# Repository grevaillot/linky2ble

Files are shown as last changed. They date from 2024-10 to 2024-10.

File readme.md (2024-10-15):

# linky2ble

stm32wb55 based linky teleinfo to ble bridge - based on https://fumeebleue.fr/ & https://hallard.me/pitinfov12/ designs

## Preview:

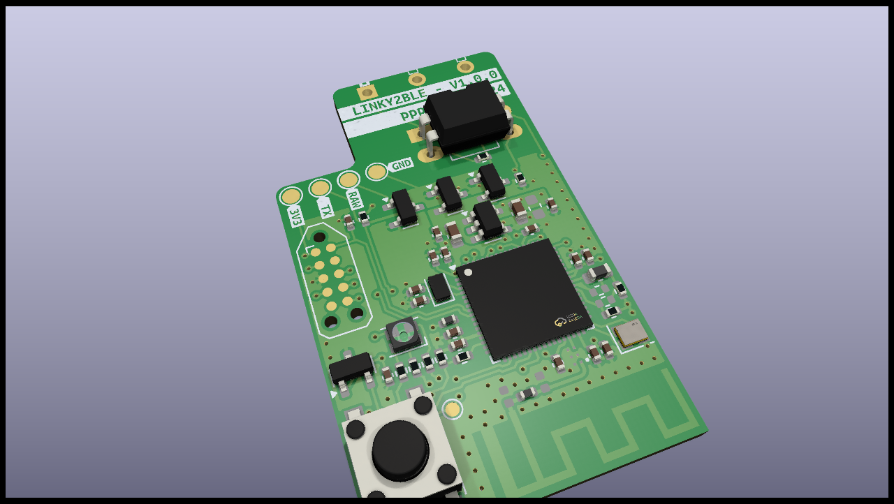
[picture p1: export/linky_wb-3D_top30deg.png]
board picture 30deg

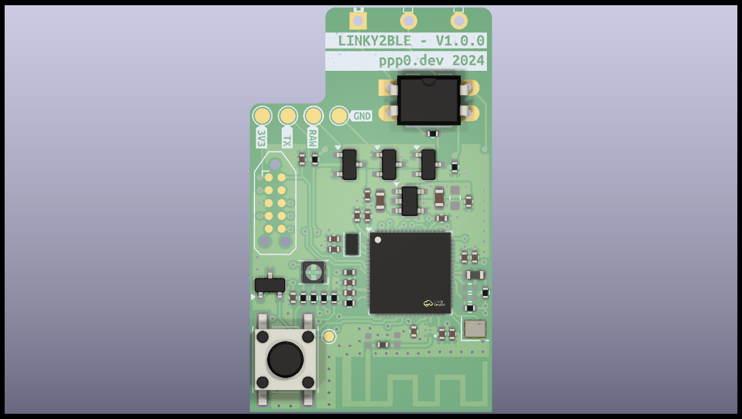
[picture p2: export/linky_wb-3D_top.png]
board picture top


## Schematics:

schematics here

## Aisler project:

https://aisler.net/p/WQYUVWAP (ordering a stencil is recommended :))

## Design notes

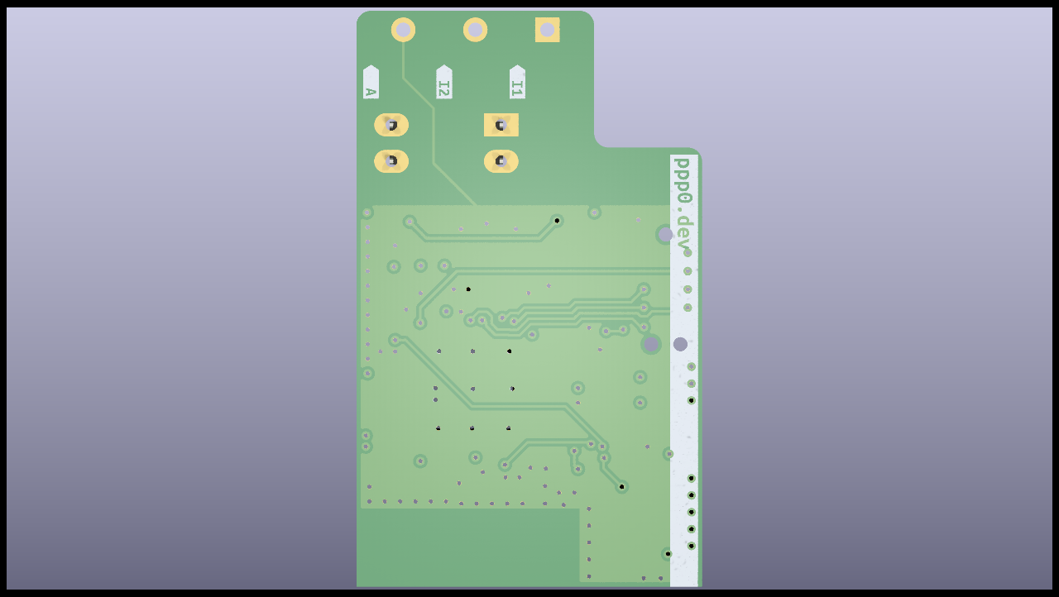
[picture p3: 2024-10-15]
export/linky_wb-3D_bottom.png

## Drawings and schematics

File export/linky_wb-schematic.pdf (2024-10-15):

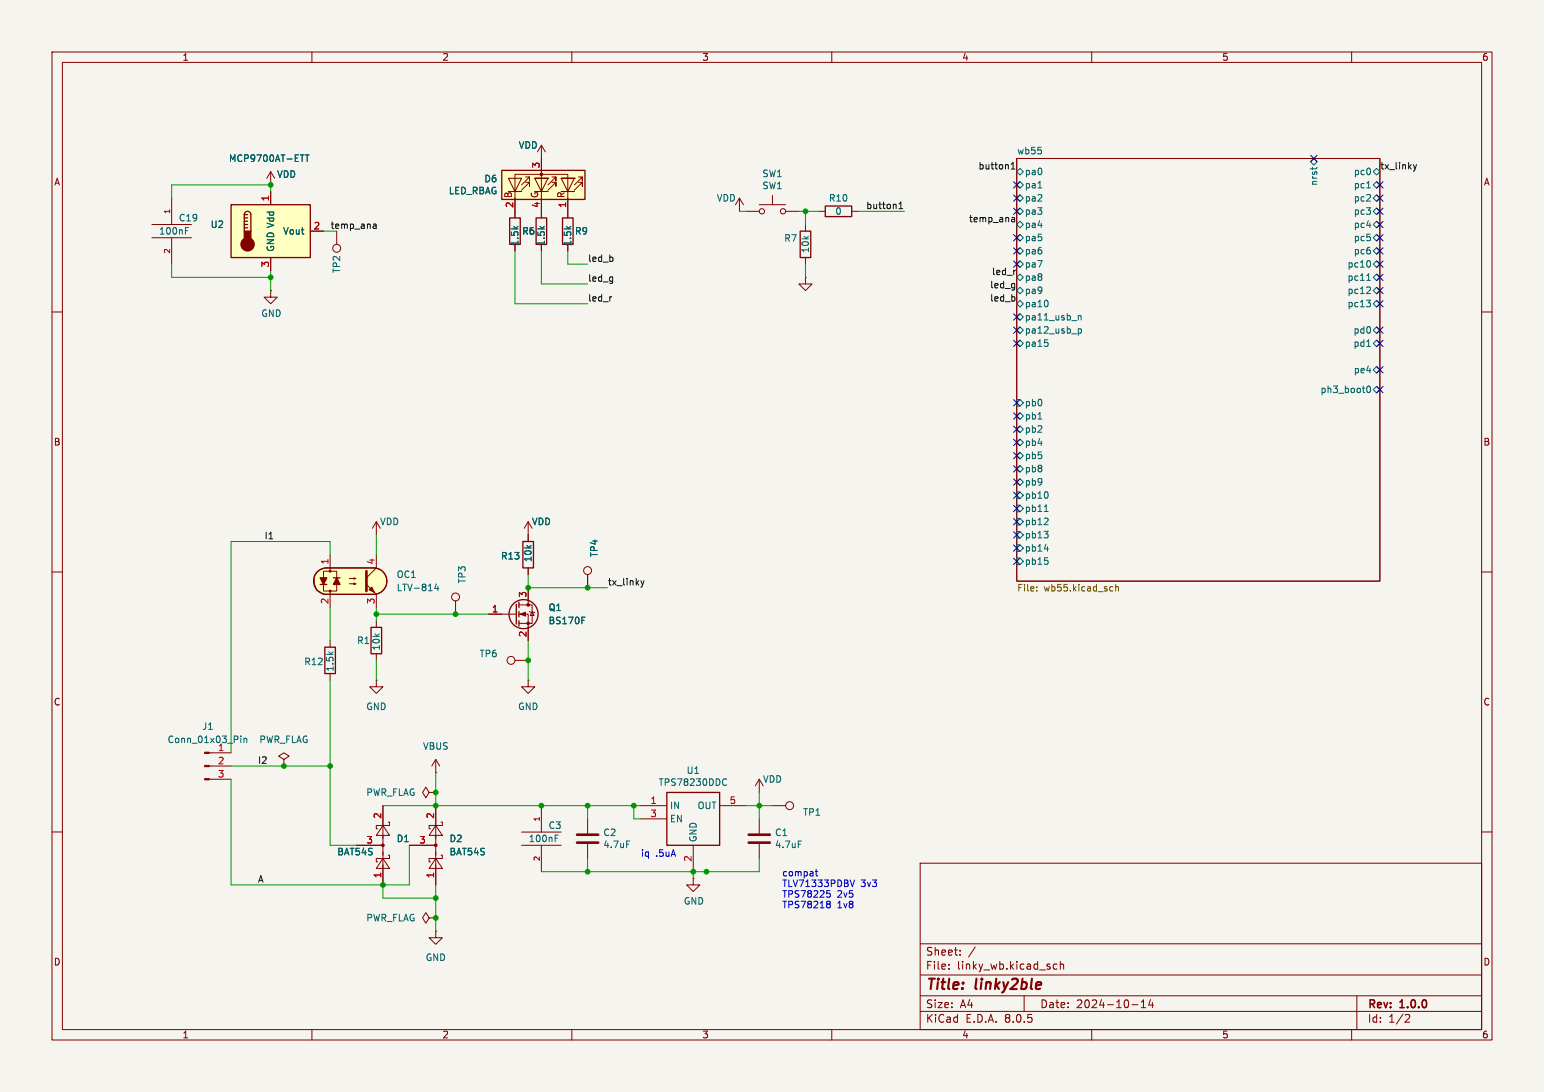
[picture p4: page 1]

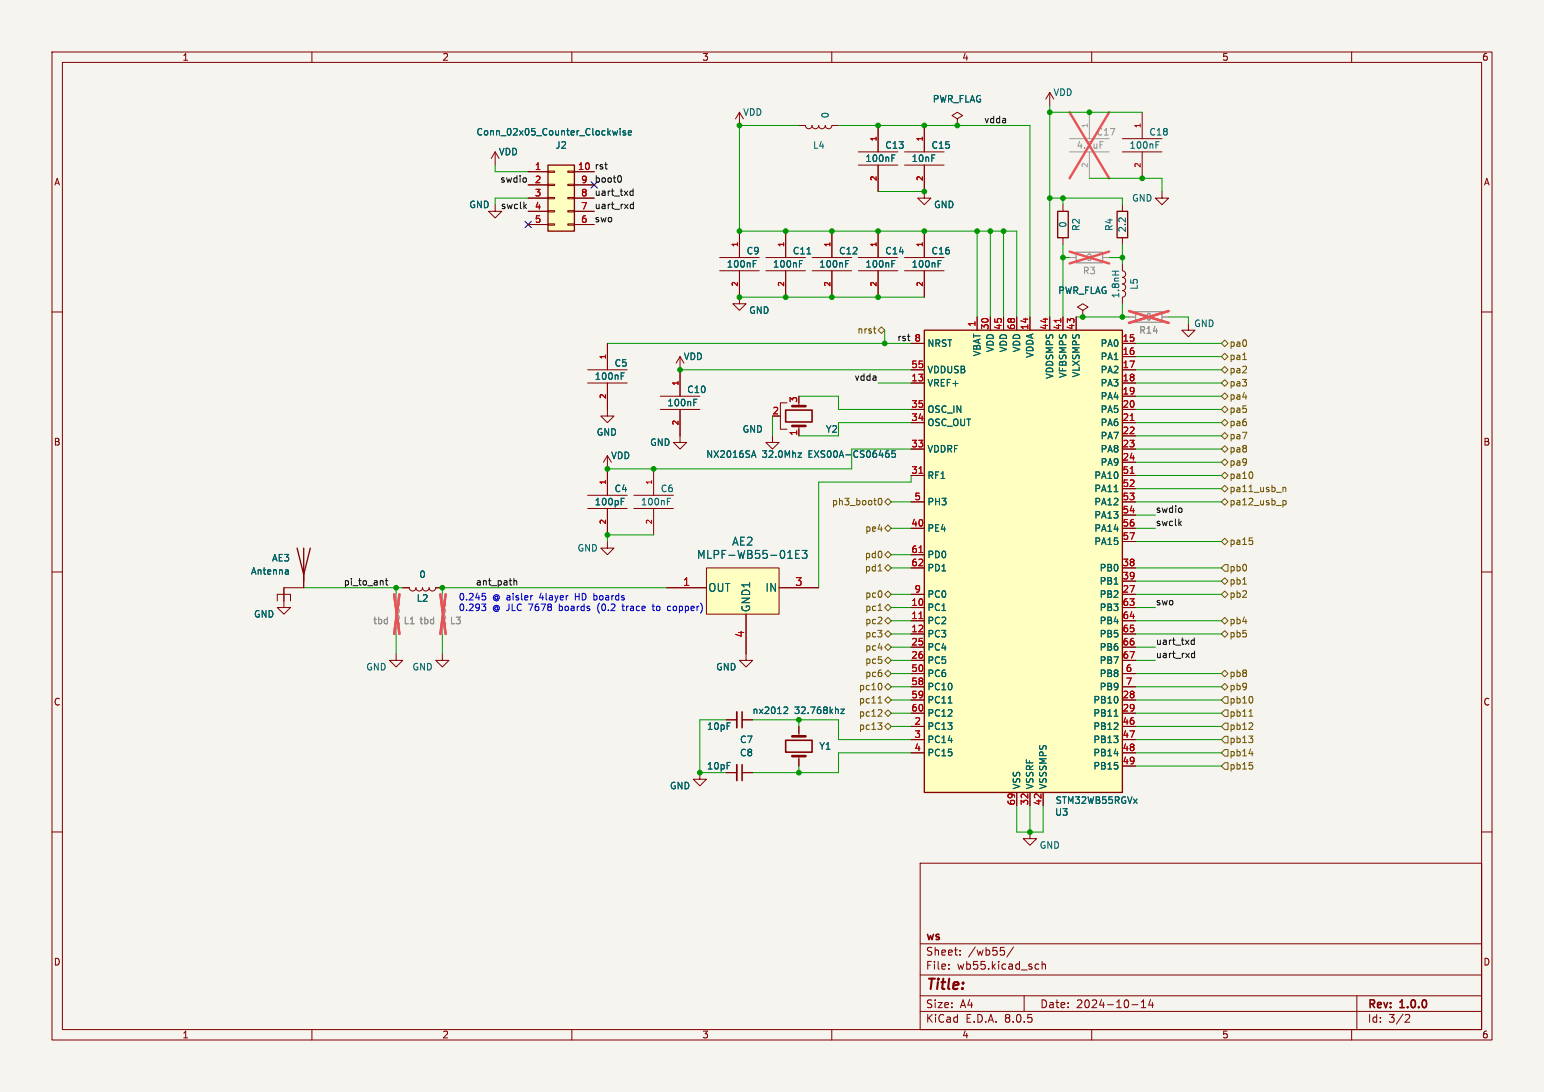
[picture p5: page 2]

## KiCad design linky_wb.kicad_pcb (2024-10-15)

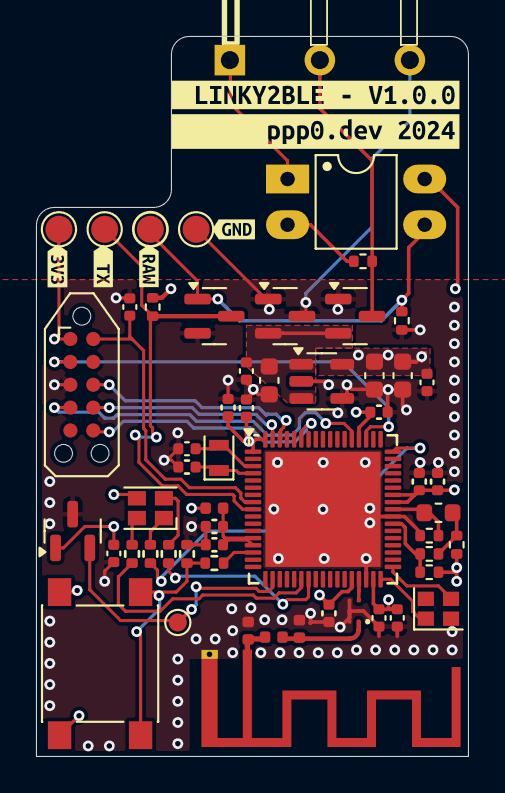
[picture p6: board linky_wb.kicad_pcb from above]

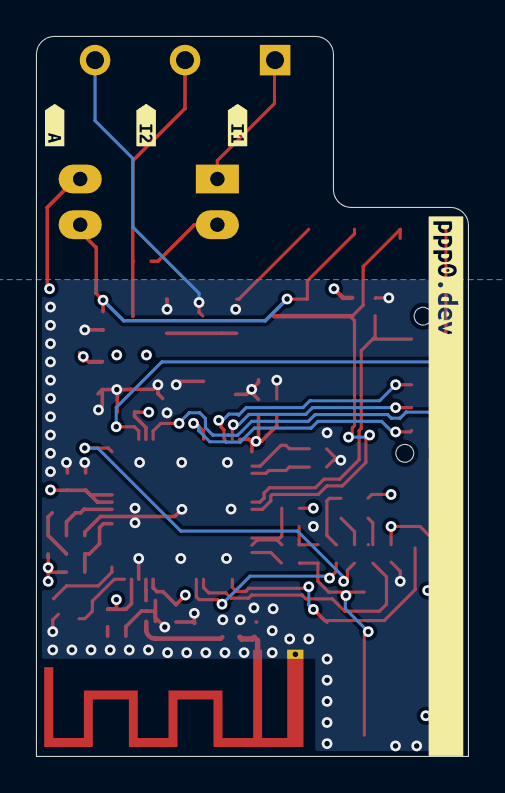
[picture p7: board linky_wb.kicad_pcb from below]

Board: 4 copper layers, 24.0 x 40.0 mm, 66 parts (4 on the bottom side), 34 nets.

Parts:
AE2: MLPF-WB55-01E3
AE3: Antenna; Texas_SWRA117D_2.4GHz_Left
C1, C2, C17: 4.7uF; C_0603_1608Metric
C3, C5, C6, C9, C10, C11, C12, C13, C14, C16, C18, C19: 100nF; C_0402_1005Metric
C4: 100pF; C_0402_1005Metric
C7, C8: 10pF; C_0402_1005Metric
C15: 10nF; C_0402_1005Metric
D1, D2: BAT54S; SOT-23
D6: LED_RBAG; LED_Cree-PLCC4_2x2mm_CW
J1: Conn_01x03_Pin; PinHeader_1x03_P2.54mm_Horizontal
J2: Conn_02x05_Counter_Clockwise; Tag-Connect_TC2050-IDC-NL_2x05_P1.27mm_Vertical
L1, L3: tbd; L_0402_1005Metric
L2, L4: 0; L_0402_1005Metric
L5: 1.8nH; L_0603_1608Metric
OC1: LTV-814; DIP-4_W7.62mm_LongPads
Q1: BS170F; SOT-23
R1, R7, R13: 10k; R_0402_1005Metric
R2, R3, R10, R14: 0; R_0402_1005Metric
R4: 2.2; R_0402_1005Metric
R5, R6, R9, R12: 1.5k; R_0402_1005Metric
SW1: SW1; SW_Push_1P1T_NO_6x6mm_H9.5mm
TP1, TP3, TP4, TP6: 5v; TestPoint_Pad_D1.5mm
TP2: TestPoint; TestPoint_Pad_D1.0mm
U1: TPS78230DDC; SOT-23-5
U2: MCP9700AT-ETT; SOT-23
U3: STM32WB55RGVx; QFN-68-1EP_8x8mm_P0.4mm_EP6.4x6.4mm
Y1: nx2012 32.768khz; Crystal_SMD_2012-2Pin_2.0x1.2mm
Y2: NX2016SA 32.0Mhz EXS00A-CS06465; Crystal_SMD_2016-4Pin_2.0x1.6mm
kibuzzard-670CFC0C: G***; kibuzzard-670CFC0C
kibuzzard-670CFC05: G***; kibuzzard-670CFC05
kibuzzard-670CFC68: G***; kibuzzard-670CFC68
kibuzzard-670CFCA8: G***; kibuzzard-670CFCA8
kibuzzard-670D18C1: G***; kibuzzard-670D18C1
kibuzzard-670D18F3: G***; kibuzzard-670D18F3
kibuzzard-670D046C: G***; kibuzzard-670D046C
kibuzzard-670D0302: G***; kibuzzard-670D0302
kibuzzard-670D0308: G***; kibuzzard-670D0308
kibuzzard-670D0311: G***; kibuzzard-670D0311

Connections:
/I1: J1.1, OC1.1
/I2: D1.3, J1.2, R12.2
/button1: R10.2, U3.15 (PA0)
/led_b: R9.1, U3.51 (PA10)
/led_g: R6.1, U3.24 (PA9)
/led_r: R5.1, U3.23 (PA8)
/temp_ana: TP2.1, U2.2 (Vout), U3.19 (PA4)
/tx_linky: Q1.3 (D), R13.2, TP4.1, U3.9 (PC0)
/wb55/ant_path: AE2.1 (OUT), L2.2, L3.2
/wb55/pi_to_ant: AE3.1 (A), L1.2, L2.1
/wb55/rst: C5.1, J2.10, U3.8 (NRST)
/wb55/swclk: J2.4, U3.56 (PA14)
/wb55/swdio: J2.2, U3.54 (PA13)
/wb55/swo: J2.6, U3.63 (PB3)
/wb55/uart_rxd: J2.7, U3.67 (PB7)
/wb55/uart_txd: J2.8, U3.66 (PB6)
/wb55/vdda: C13.1, C15.1, L4.1, U3.13 (VREF+), U3.14 (VDDA)
GND: AE2.2 (GND4), AE2.4 (GND1), AE2.5 (GND2), AE2.6 (GND3), AE3.2 (gnd), C1.2, C2.2, C3.2, C4.2, C5.2, C6.2, C7.2, C8.2, C9.2, C10.2, C11.2, C12.2, C13.2, C14.2, C15.2, C16.2, C17.2, C18.2, C19.2, D1.1, D2.1, D2.3, J1.3, J2.3, L1.1, L3.1, Q1.2 (S), R1.2, R7.2, R14.2, TP6.1, U1.2 (GND), U1.4 (GND), U2.3 (GND), U3.32 (VSSRF), U3.42 (VSSSMPS), U3.69 (VSS), Y2.2
unnamed: AE2.3 (IN), U3.31 (RF1)
unnamed: D6.2 (BK), R5.2
unnamed: D6.4 (GK), R6.2
unnamed: D6.1 (RK), R9.2
unnamed: L5.1, R3.2, R4.2
unnamed: OC1.2, R12.1
unnamed: OC1.3, Q1.1 (G), R1.1, TP3.1
unnamed: R7.1, R10.1, SW1.1
unnamed: U3.35 (OSC_IN), Y2.3
unnamed: U3.34 (OSC_OUT), Y2.1
unnamed: C7.1, U3.3 (PC14), Y1.2
unnamed: C8.1, U3.4 (PC15), Y1.1
unnamed: R2.2, R3.1, U3.41 (VFBSMPS)
unnamed: L5.2, R14.1, U3.43 (VLXSMPS)
VBUS: C2.1, C3.1, D1.2, D2.2, U1.1 (IN), U1.3 (EN)
VDD: C1.1, C4.1, C6.1, C9.1, C10.1, C11.1, C12.1, C14.1, C16.1, C17.1, C18.1, C19.1, D6.3 (A), J2.1, L4.2, OC1.4, R2.1, R4.1, R13.1, SW1.2, TP1.1, U1.5 (OUT), U2.1 (Vdd), U3.1 (VBAT), U3.30 (VDD), U3.33 (VDDRF), U3.44 (VDDSMPS), U3.45 (VDD), U3.55 (VDDUSB), U3.68 (VDD)

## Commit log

2024-10-14 oups, belle pause du midi
    [linky_wb.kicad_pcb, linky_wb.kicad_sch, wb55.kicad_sch]
2024-10-14 erc/drc: fixes & regen
    [linky_wb.kicad_pcb]
2024-10-14 schematics: cleanup bom
    [linky_wb.kicad_sch, wb55.kicad_sch]
2024-10-14 1.0.0 boards sent to production
    [linky_wb.kicad_pcb, linky_wb.kicad_sch, wb55.kicad_sch]
2024-10-15 cleanups, exclude some drcs, fix antenna symbol to avoid ground disconnection, tweak ci
    [linky_wb.kicad_pcb, linky_wb.kicad_sch, wb55.kicad_sch]

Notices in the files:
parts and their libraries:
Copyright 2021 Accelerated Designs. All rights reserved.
